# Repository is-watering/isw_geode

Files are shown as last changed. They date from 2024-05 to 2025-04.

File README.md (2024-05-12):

# ISW-GEODE
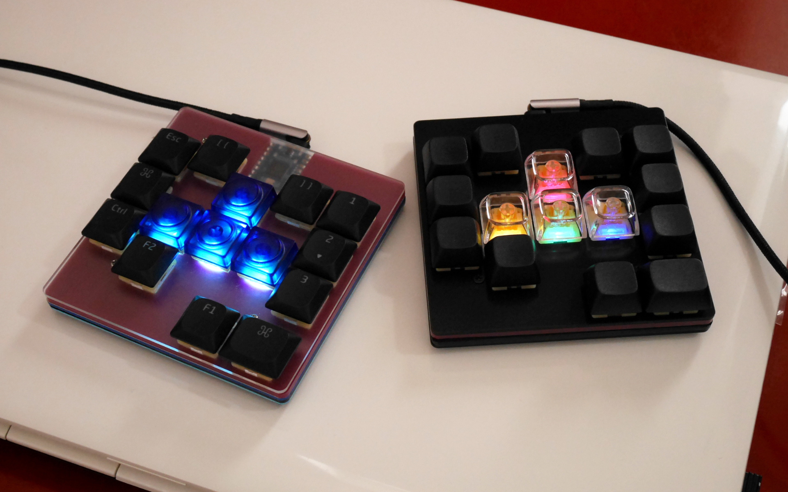
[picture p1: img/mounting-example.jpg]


ISW-GEODE is a gaming macro pad designed primarily for playing Minecraft.

[Build guide](doc/buildguide.md)

## Dependencies (KiCad)
* [is-watering/isw-kbd-lib](https://github.com/is-watering/isw-kbd-lib)
* [Salicylic-acid3/KiCAD_FootPrint](https://github.com/Salicylic-acid3/KiCAD_FootPrint)
* [koktoh/BrownSugar_KBD_KiCad_Library](https://github.com/koktoh/BrownSugar_KBD_KiCad_Library)

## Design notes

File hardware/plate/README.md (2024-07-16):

## Recommended format
Name                        |Material |Thickness      |Notes
----------------------------|---------|---------------|-----
Switch plate                |-        |1.6mm or 2.0mm |
Bottom plate                |-        |1.2mm - 2.0mm  |
Middle plate A              |Acrylic  |3.0mm          |
Middle plate B              |Acrylic  |2.0mm          |

## Notes
* Acrylic plates may have gaps between plates due to tolerances. In that case, please adjust by inserting foam (EVA, silicone, etc.) between the two.

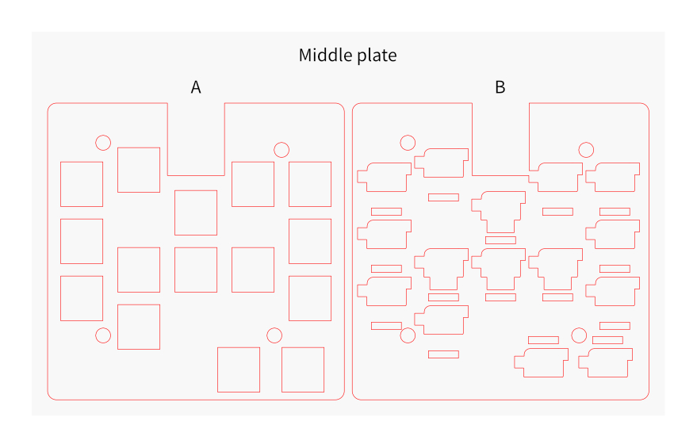
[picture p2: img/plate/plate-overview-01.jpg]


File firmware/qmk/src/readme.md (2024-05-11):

# isw_geode

isw_geode

*A short description of the keyboard/project*

* Keyboard Maintainer: [is_watering](https://github.com/is_watering)
* Hardware Supported: *The PCBs, controllers supported*
* Hardware Availability: *Links to where you can find this hardware*

Make example for this keyboard (after setting up your build environment):

    make isw_geode:default

Flashing example for this keyboard:

    make isw_geode:default:flash

See the [build environment setup](https://docs.qmk.fm/#/getting_started_build_tools) and the [make instructions](https://docs.qmk.fm/#/getting_started_make_guide) for more information. Brand new to QMK? Start with our [Complete Newbs Guide](https://docs.qmk.fm/#/newbs).

## Bootloader

Enter the bootloader in 3 ways:

* **Bootmagic reset**: Hold down the key at (0,0) in the matrix (usually the top left key or Escape) and plug in the keyboard
* **Physical reset button**: Briefly press the button on the back of the PCB - some may have pads you must short instead
* **Keycode in layout**: Press the key mapped to `QK_BOOT` if it is available

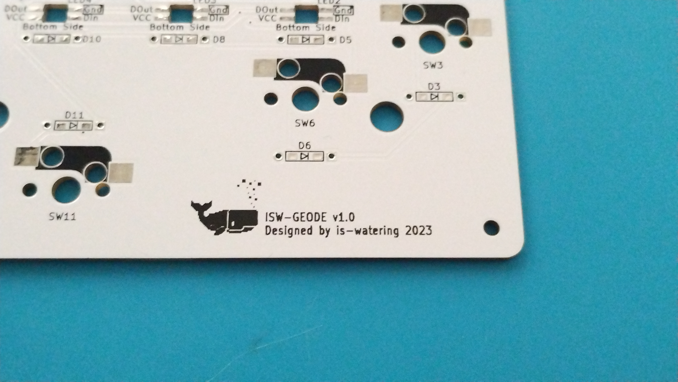
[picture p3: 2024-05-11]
firmware/qmk/evidence/evidence.jpg

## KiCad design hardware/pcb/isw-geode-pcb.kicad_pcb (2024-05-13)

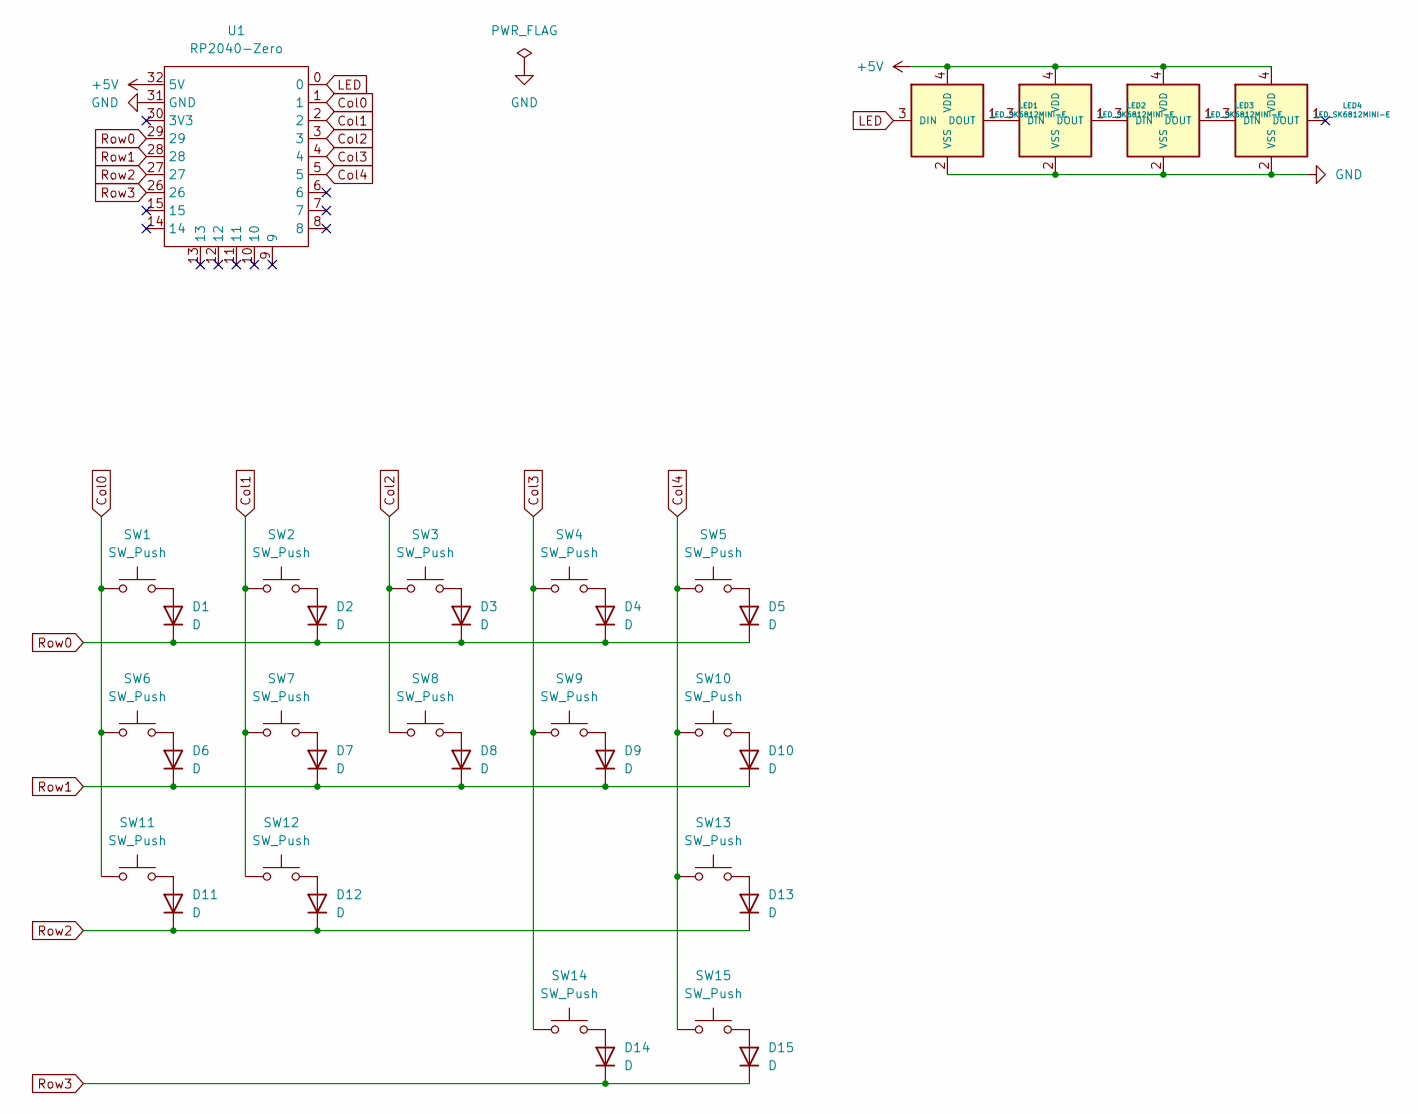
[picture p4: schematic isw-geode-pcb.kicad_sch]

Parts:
D1, D2, D3, D4, D5, D6, D7, D8, D9, D10, D11, D12, D13, D14, D15: D; Diode_TH_SMD
LED1, LED2, LED3, LED4: LED_SK6812MINI-E; LED_SK6812MINI-E_BL
SW1, SW2, SW3, SW4, SW5, SW6, SW7, SW8, SW9, SW10, SW11, SW12, SW13, SW14, SW15: SW_Push; CherryMX_Hotswap_1u
U1: RP2040-Zero; RP2040-Zero-THT

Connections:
+5V: LED1.4 (VDD), LED2.4 (VDD), LED3.4 (VDD), LED4.4 (VDD), U1.32 (5V)
Col0: SW1.1, SW6.1, SW11.1, U1.1
Col1: SW2.1, SW7.1, SW12.1, U1.2
Col2: SW3.1, SW8.1, U1.3
Col3: SW4.1, SW9.1, SW14.1, U1.4
Col4: SW5.1, SW10.1, SW13.1, SW15.1, U1.5
GND: LED1.2 (VSS), LED2.2 (VSS), LED3.2 (VSS), LED4.2 (VSS), U1.31 (GND)
LED: LED1.3 (DIN), U1.0
unnamed: D1.2 (A), SW1.2
unnamed: D2.2 (A), SW2.2
unnamed: D3.2 (A), SW3.2
unnamed: D4.2 (A), SW4.2
unnamed: D5.2 (A), SW5.2
unnamed: D6.2 (A), SW6.2
unnamed: D7.2 (A), SW7.2
unnamed: D8.2 (A), SW8.2
unnamed: D9.2 (A), SW9.2
unnamed: D10.2 (A), SW10.2
unnamed: D11.2 (A), SW11.2
unnamed: D12.2 (A), SW12.2
unnamed: D13.2 (A), SW13.2
unnamed: D14.2 (A), SW14.2
unnamed: D15.2 (A), SW15.2
unnamed: LED1.1 (DOUT), LED2.3 (DIN)
unnamed: LED2.1 (DOUT), LED3.3 (DIN)
unnamed: LED3.1 (DOUT), LED4.3 (DIN)
Row0: D1.1 (K), D2.1 (K), D3.1 (K), D4.1 (K), D5.1 (K), U1.29
Row1: D6.1 (K), D7.1 (K), D8.1 (K), D9.1 (K), D10.1 (K), U1.28
Row2: D11.1 (K), D12.1 (K), D13.1 (K), U1.27
Row3: D14.1 (K), D15.1 (K), U1.26

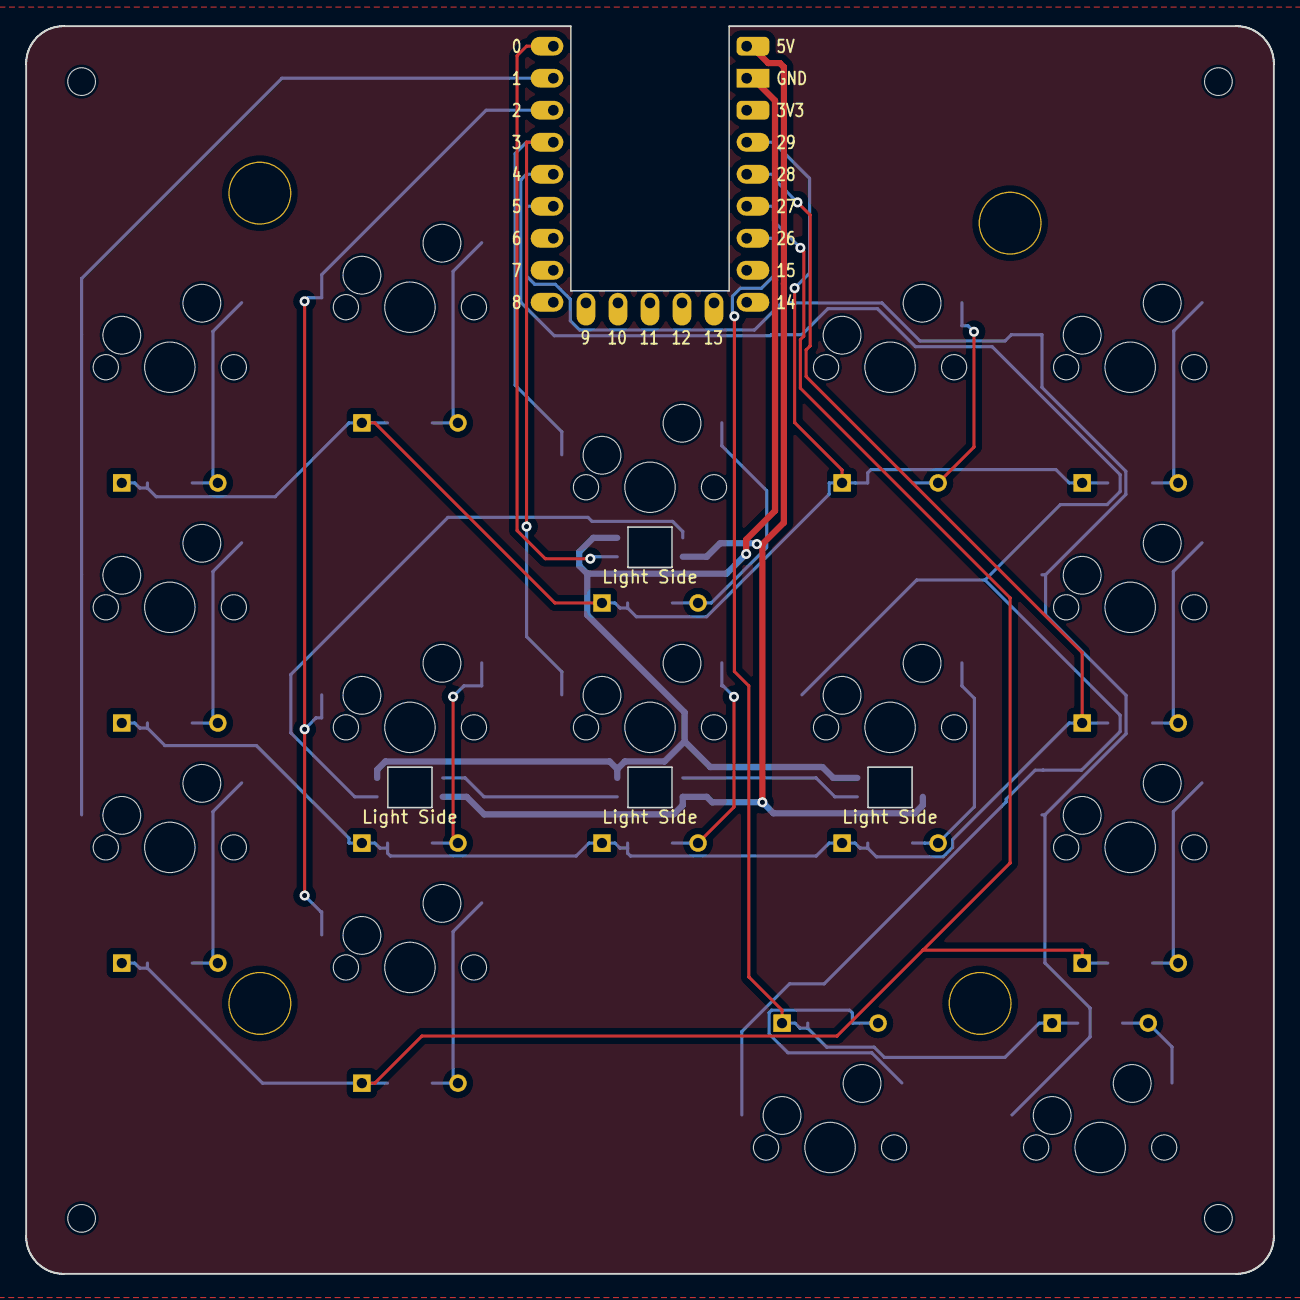
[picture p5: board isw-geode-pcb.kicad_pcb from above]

Board: 2 copper layers, 99.0 x 99.0 mm, 43 parts (1 on the bottom side), 30 nets.

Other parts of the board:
Ref01, Ref02, Ref03, Ref04: Val01; m2_Spacer_Hole
Ref11, Ref12, Ref13, Ref14: Val02; m2_Screw_Hole

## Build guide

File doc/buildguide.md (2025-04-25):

# Build guide

## Parts
Name                     |Quantity |Notes
-------------------------|---------|-----
PCB                      |1        |[Here's the data](https://github.com/is-watering/isw_geode/tree/main/hardware/pcb)
Switch plate             |1        |[Here's the data](https://github.com/is-watering/isw_geode/tree/main/hardware/plate)
Bottom plate             |1        |[Here's the data](https://github.com/is-watering/isw_geode/tree/main/hardware/plate)
SK6812 MINI-E leds       |4        |
1N4148W diodes           |15       |
Kailh hotswap sockets    |15       |
RP2040-Zero              |1        |
M2x4mm screws            |8        |
M2x7mm spacers           |4        |[HIROSUGI NET](https://www.hirosugi-net.co.jp/shop/c/c10141012/)

## Build PCB

### [Leds](https://github.com/is-watering/isw-kbd-building-tips/blob/main/doc/en/soldering-sk6812mini-e.md)

### [Diodes](https://github.com/is-watering/isw-kbd-building-tips/blob/main/doc/en/soldering-1n4148w.md)

### [Hotswap sockets](https://github.com/is-watering/isw-kbd-building-tips/blob/main/doc/en/soldering-cpg151101s11.md)

### RP2040-Zero
It is recommended to check whether the firmware can be written to the microcontroller in advance.
* [Remap](https://remap-keys.app/catalog/uf4aIRy3BQslvcxSSvND)
* [Soure code](https://github.com/is-watering/isw_geode/tree/main/firmware)

Solder the microcontroller from the top of the PCB, face down, using surface mount soldering.  
[Learn more about how to solder microcontrollers](https://github.com/is-watering/isw-kbd-building-tips/blob/main/doc/en/surfacemount-rp2040-zero.md)
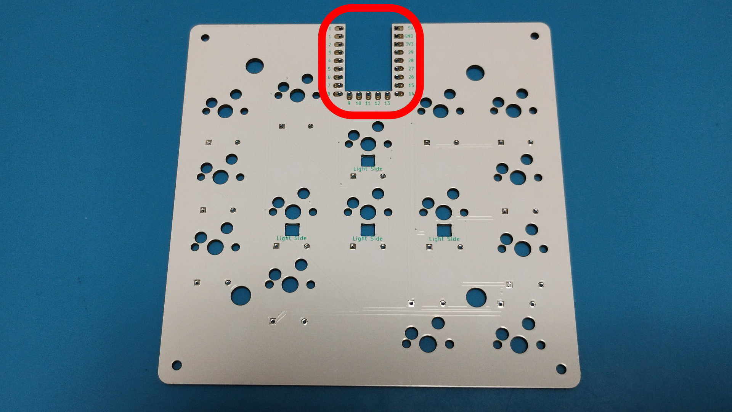
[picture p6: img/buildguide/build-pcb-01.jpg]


## Build Case
Use a 4mm screw to secure the 7mm spacer.  
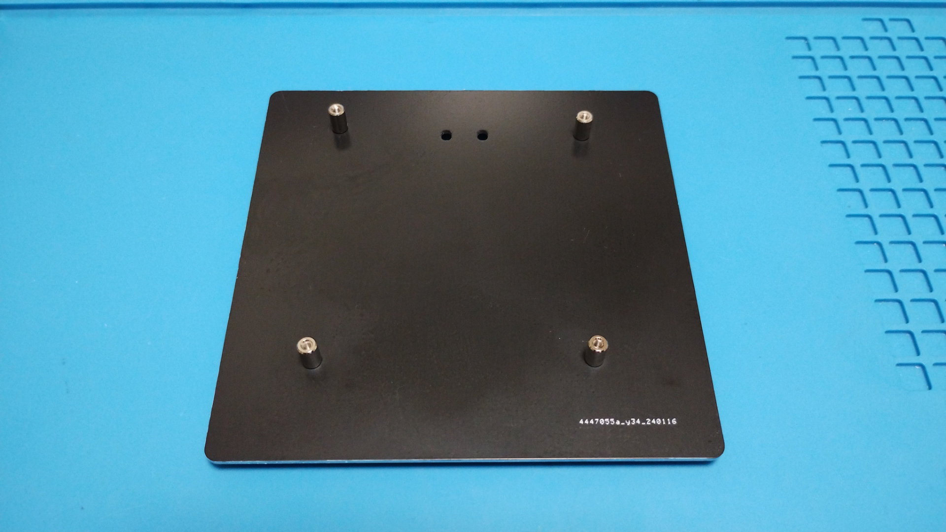
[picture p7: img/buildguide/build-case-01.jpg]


Place the PCB on the bottom plate.  
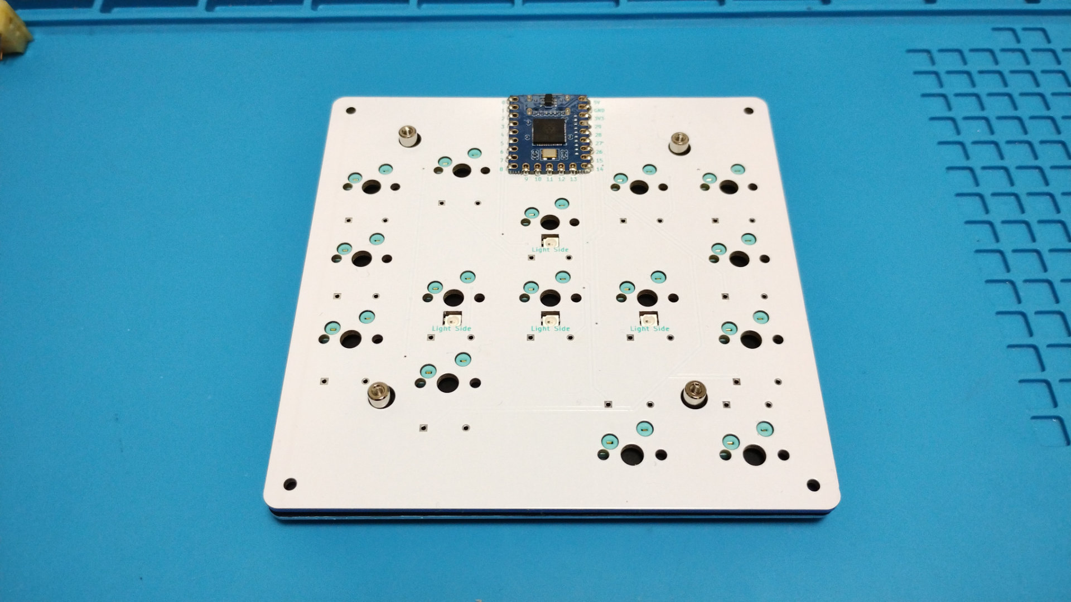
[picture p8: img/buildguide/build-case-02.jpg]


Place switch plate on the PCB. It is easier to align the key switches if they are attached to the four corners.  
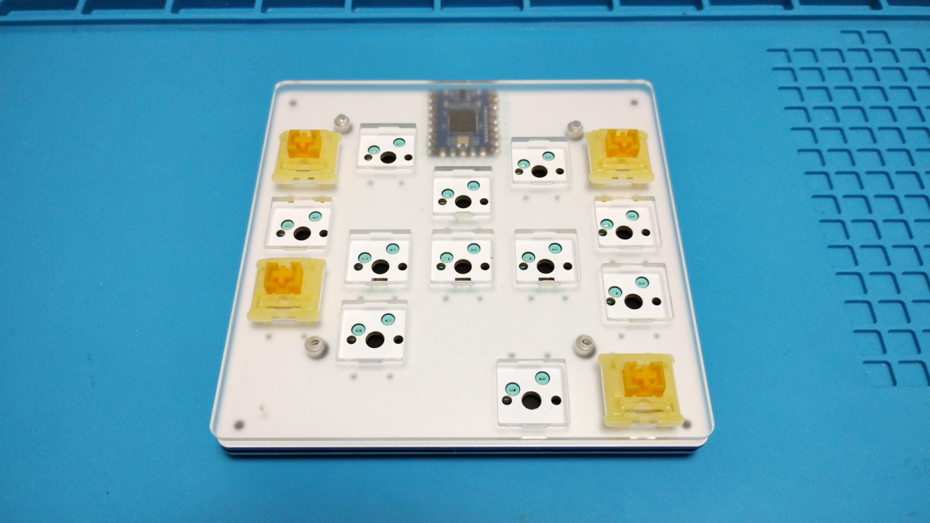
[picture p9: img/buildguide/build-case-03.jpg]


Use a 4mm screw to secure the switch plate.Fix the switch plate using a 4mm screw.  
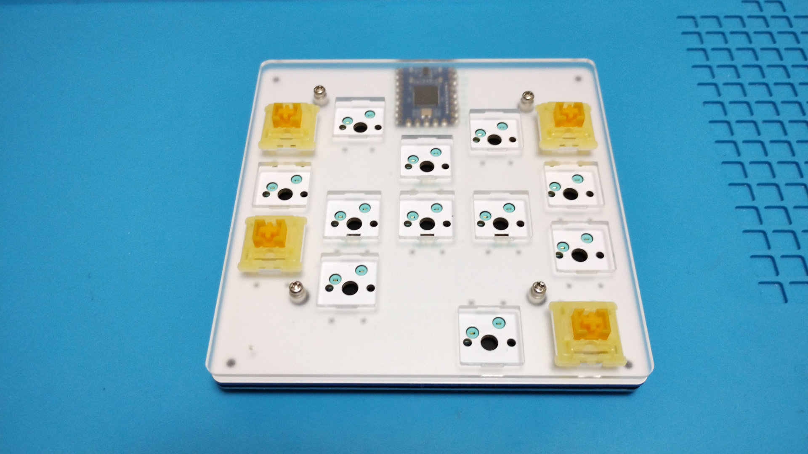
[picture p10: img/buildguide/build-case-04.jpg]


Attach a key switch of your choice.  
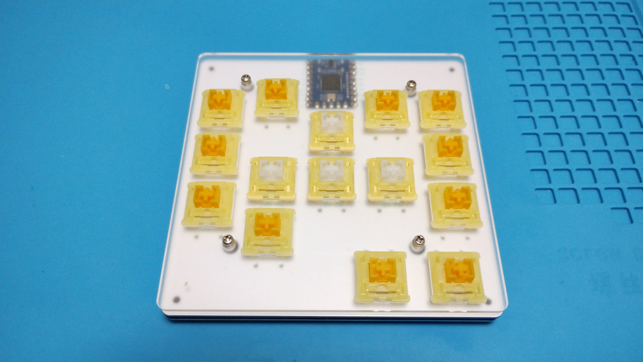
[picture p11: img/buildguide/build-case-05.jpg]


Attach a keycap of your choice to complete the process!  
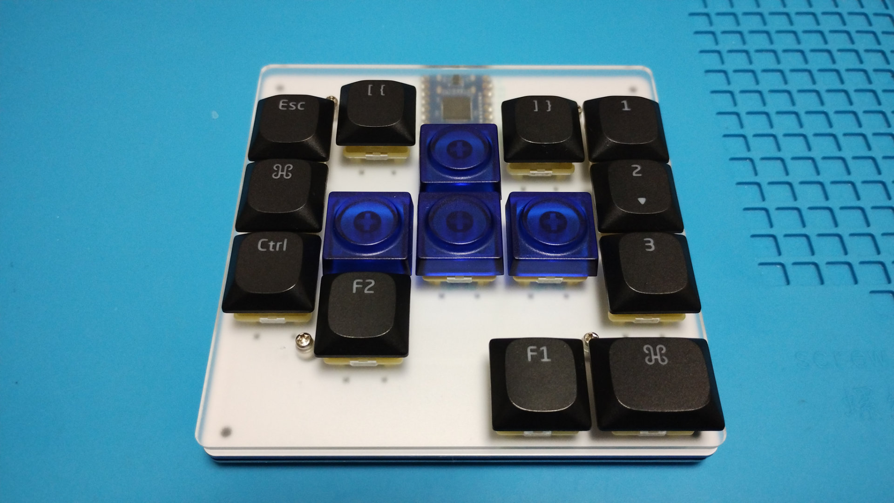
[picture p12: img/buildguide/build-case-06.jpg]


Congratulations on the completion!  
Please be proud of it on social networking sites!  
`#isw_kbd`
